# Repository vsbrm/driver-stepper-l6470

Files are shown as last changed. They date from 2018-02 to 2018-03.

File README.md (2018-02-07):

# Stepper motor driver board

This is the simple stepper motor driver board which built on L6470 IC.
This IC can rule one bipolar stepper motor in up to 1/128 microstepping mode
with current control, overcurrent protection and set up by SPI interface.
This board can be used as completed part of stepper motor control system.

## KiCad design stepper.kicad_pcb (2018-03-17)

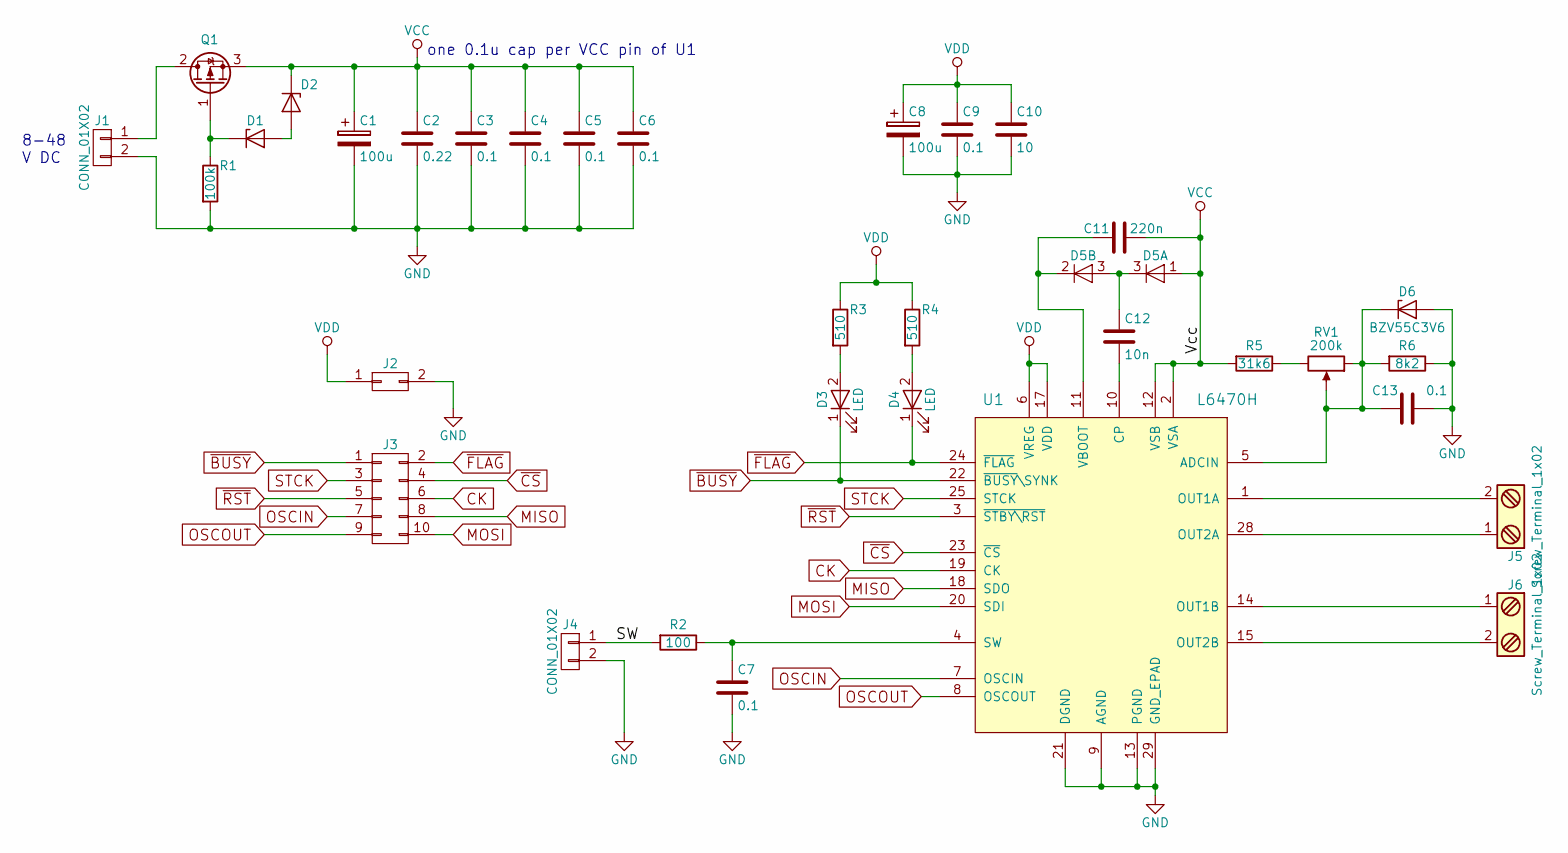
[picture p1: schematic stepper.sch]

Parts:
C1, C8: 100u; CP_Radial_D10.0mm_P3.50mm; Voltage 100
C2: 0.22; C_0805; Voltage 100
C3, C4, C5, C6, C9: 0.1; C_0805; Voltage 25
C7, C13: 0.1; C_0805; Voltage 6.3
C10: 10; C_0805; Voltage 25
C11: 220n; C_0805; Voltage 16v
C12: 10n; C_0805; Voltage 50v
D1, D2: BZV55C10; D_MiniMELF
D3, D4: LED; LED_0805
D5: BAV99; SOT-23
D6: BZV55C3V6; D_MiniMELF
J1, J4: CONN_01X02; Pin_Header_Straight_1x02_Pitch2.54mm
J2: CONN_02X01; Pin_Header_Straight_1x02_Pitch2.54mm
J3: CONN_02X05; Pin_Header_Straight_2x05_Pitch2.54mm
J5, J6: Screw_Terminal_1x02; TerminalBlock_bornier-2_P5.08mm
Q1: IRFR5410; TO-252-2
R1: 100k; R_0805
R2: 100; R_0805
R3, R4: 510; R_0805
R5: 31k6; R_0805
R6: 8k2; R_0805
RV1: 200k; Potentiometer_Trimmer_Bourns_3266W
U1: L6470H; HTSSOP-28_4.4x9.7mm_Pitch0.65mm_ThermalPad

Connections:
/SW: J4.1, R2.2
CK: J3.6, U1.19 (CK)
GND: C1.2, C2.2, C3.2, C4.2, C5.2, C6.2, C7.2, C8.2, C9.2, C10.2, C13.1, D6.2 (A), J1.2, J2.2, J4.2, R1.2, R6.1, U1.9 (AGND), U1.13 (PGND), U1.21 (DGND), U1.27 (PGND), U1.29 (GND_EPAD)
MISO: J3.8, U1.18 (SDO)
MOSI: J3.10, U1.20 (SDI)
unnamed: C7.1, R2.1, U1.4 (SW)
unnamed: C11.1, D5.2 (K), U1.11 (VBOOT)
unnamed: C12.1, D5.3 (K)
unnamed: C12.2, U1.10 (CP)
unnamed: C13.2, D6.1 (K), R6.2, RV1.1, RV1.2, U1.5 (ADCIN)
unnamed: D1.1 (K), Q1.1 (G), R1.1
unnamed: D1.2 (A), D2.2 (A)
unnamed: D3.2 (A), R3.2
unnamed: D4.2 (A), R4.2
unnamed: J1.1, Q1.2 (D)
unnamed: J5.1, U1.28 (OUT2A)
unnamed: J5.2, U1.1 (OUT1A)
unnamed: J6.1, U1.14 (OUT1B)
unnamed: J6.2, U1.15 (OUT2B)
unnamed: R5.1, RV1.3
OSCIN: J3.7, U1.7 (OSCIN)
OSCOUT: J3.9, U1.8 (OSCOUT)
STCK: J3.3, U1.25 (STCK)
VCC: C1.1, C2.1, C3.1, C4.1, C5.1, C6.1, C11.2, D2.1 (K), D5.1 (A), Q1.3 (S), R5.2, U1.2 (VSA), U1.12 (VSB), U1.16 (VSB), U1.26 (VSA)
VDD: C8.1, C9.1, C10.1, J2.1, R3.1, R4.1, U1.6 (VREG), U1.17 (VDD)
~BUSY: D3.1 (K), J3.1, U1.22 (~BUSY~\SYNK)
~CS: J3.4, U1.23 (~CS)
~FLAG: D4.1 (K), J3.2, U1.24 (~FLAG)
~RST: J3.5, U1.3 (~STBY\RST)

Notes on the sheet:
8-48 V DC
one 0.1u cap per VCC pin of U1

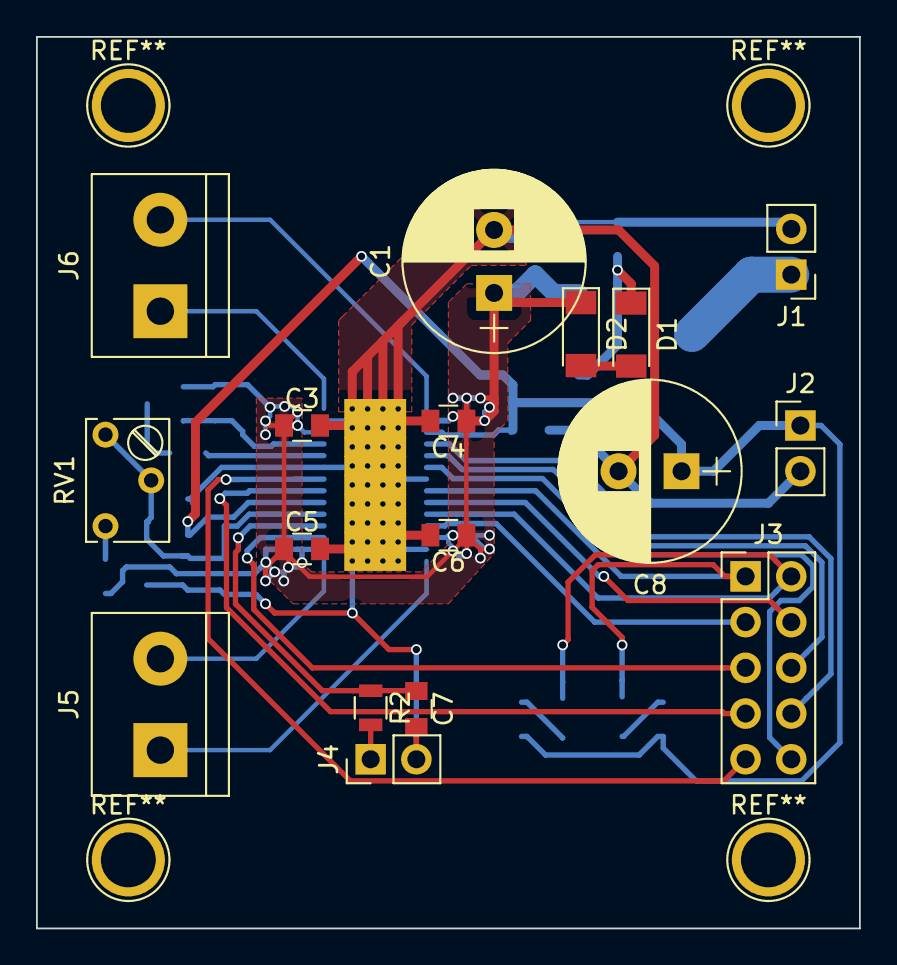
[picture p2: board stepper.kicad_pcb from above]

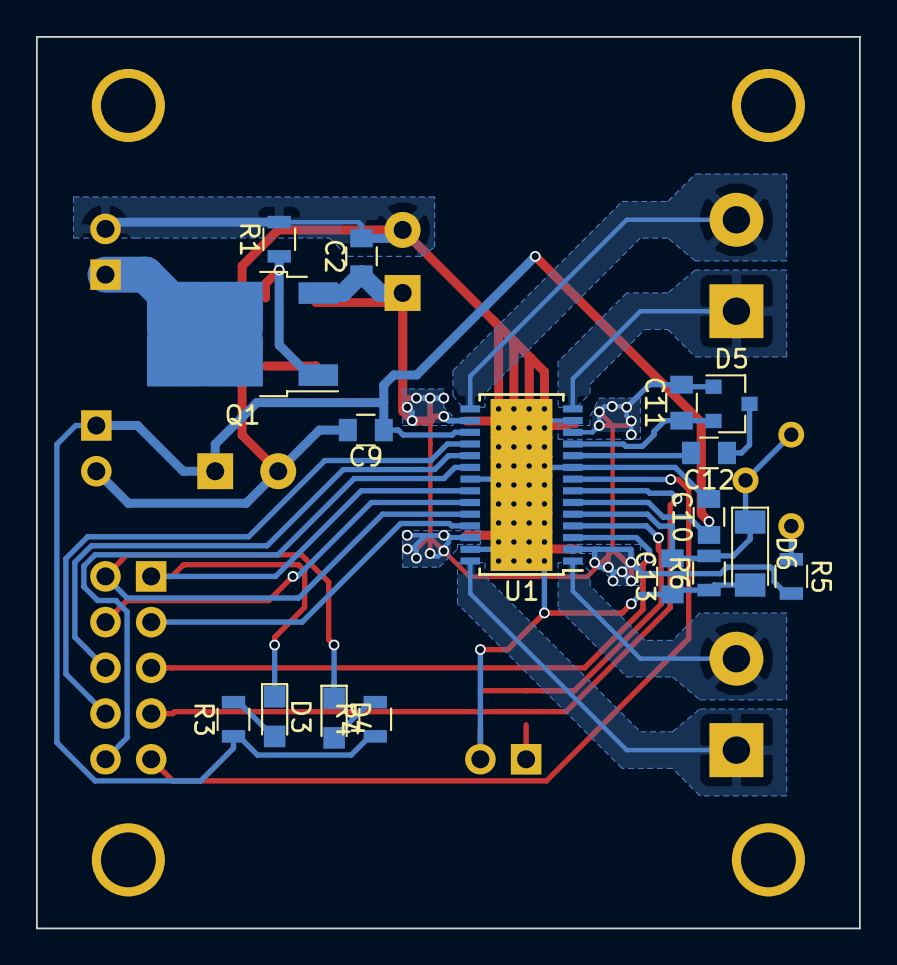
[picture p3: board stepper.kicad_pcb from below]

Board: 2 copper layers, 45.7 x 49.5 mm, 34 parts (17 on the bottom side), 29 nets.

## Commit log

2018-03-11 Values
    Viable version of schematic. Calculated values and attached footprints.
    [stepper.kicad_pcb, stepper.sch]
2018-03-11 Caps
    Some changes in VCC filtration capcitors.
    [stepper.kicad_pcb, stepper.sch]
2018-03-17 PCB
    Routed PCB
    [stepper.kicad_pcb, stepper.sch]
